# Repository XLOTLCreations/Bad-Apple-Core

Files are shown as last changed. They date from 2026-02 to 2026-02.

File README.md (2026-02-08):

Project Disclaimer and Overview

- This project has been designed by me with the sole obsession of trying to run the infamous 'Bad Apple' video (so the name) as resourcefully with least computational power as one can compared to a previous project (with relatively much more computation and features, titled 'Bad Apple' original) therefore boiling it down to it's only 'Core' aspect of video playback and from scratch without any references to any existing similar projects anywhere. All the documentation (including this one) is compiled and handwritten with outmost human accuracy without the help of AI, with that said the included Arduino test sketches and Python script are with the AI help.

- This doc helps the reader navigate through documents to develop/mod, verify and manufacture this project from start to finish. Project files include Schematic, PCB Layout and reference pictures to recreate my setup and my results, for which adhering to the highlighted sequence of steps in respective areas is highly advised. 

- For the ones who received this project from me as a gift, please ignore Doc1 and proceed with Doc2, as Doc1 strictly talks about virgin boot of this board and only requires to be done once per board.

- Project is open source software and hardware, please refer the included ECAD files for hardware insight. To my fellow hardware design engineers and experts, any design improvement suggestions are more than welcome. For the ones not so learned in the ways of hardware, may this project enlighten you with some new knowledge that you can take home. 

🎯 Project Specifications:
I am listing basic specifications for someone to decide here itself if they are interested in continuing further. No soldering required. Please note that project was designed with the intention of learning for new comers/beginners, do not @me for something the project was clearly not meant to achieve which is complexity and obscurity. Intended for kids learning in school, present it at your 'show and tell', tell me how it goes.

Connections: USB-C (Full-Speed), ICSP header (no-fit),\
Main Processor: Atmega32U4,\
Human Machine Interface: 4x tactile buttons for interaction (active LOW),\
Output: 12x9 Charlie Plexed LED Matrix driven using IS31FL3731-QF over I2C,\
Storage: W25Q128JVP 16MByte QSPI NOR Flash (video frames, game assets),\
System Working Voltage: Vsys=3.3V,\
System Clock: 8MHz,\
(over-clocking/over-volting not advised)

- Lastly, this project has no version or revision history (call me lucky to have gotten everything right the first time itself) and has an elder project by the name 'Bad Apple' which was reduced down to it's core functionality hence the reasoning behind naming this second project as 'Bad Apple Core'. Please refer to that project with several advancements and higher complexity, if not up yet then stay tuned as the project is ready and working, I am busy documenting it.

HAVE FUN LEARNING - PLAYING - EXPERIMENTING - DEVELOPING.............

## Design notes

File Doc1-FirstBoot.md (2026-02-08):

***IF YOU SKIPPED OVER 'README' PLEASE READ FIRST FOR PROJECT INSIGHT***

Programmer Used:  Arduino Nano as ISP\
Interface:  4x tactile switch push buttons\
            Up: D0 (PD2, physical pin 20)\
            Down: A5 (PF0, physical pin 41, ADC0)\
            Right: A4 (PF1, physical pin 40, ADC1)\
            Left: D11 (PB7, physical pin 12)

Notes: \
A. ISP and ICSP are one and the same, ICSP is the physical header and ISP the protocol, \
B. ISP First Boot @1MHz ~10-15 Seconds, any more time elapsed might hint at (but not necessarily) a faulty behavior, \
C. In Device Manager 'Bad Apple Core' board will enumerate as 'Arduino Leonardo' once connected through USB post finishing of the steps in this Doc1 document. 

Parts List:
Arduino NANO/UNO (for burning), respective Arduino model cable to connect to your host PC, small breadboard, jumper wires, 3x 1KOhm 1/4Watt 1% (preferred but not strict) and 3x 2KOhm 1/4Watt 1% (preferred but not strict) through hole resistors. I used 1/4W resistors being the most ubiquitious but you can easily opt to use pretty much anything below or above 1/4W power as the signals are essentially very low power themselves.

Steps:
1.0 - We need to create a 'Custom Board Definition' for our custom 'Bad Apple Core' board
1.1 - Locate your Arduino installation folder:
    Windows: `C:\Users\[YourName]\AppData\Local\Arduino15\`

1.2 - Navigate to: `packages/arduino/hardware/avr/[version]/`

1.3 - Edit `boards.txt` and add this at the end:
##############################################################
# Custom Atmega32U4 3.3V 8MHz
##############################################################

atmega32u4_33v8mhz.name=Atmega32U4 3.3V 8MHz

atmega32u4_33v8mhz.vid.0=0x2341
atmega32u4_33v8mhz.pid.0=0x8036
atmega32u4_33v8mhz.vid.1=0x2341
atmega32u4_33v8mhz.pid.1=0x0036

atmega32u4_33v8mhz.upload.tool=avrdude
atmega32u4_33v8mhz.upload.tool.default=avrdude
atmega32u4_33v8mhz.upload.protocol=avr109
atmega32u4_33v8mhz.upload.maximum_size=28672
atmega32u4_33v8mhz.upload.maximum_data_size=2560
atmega32u4_33v8mhz.upload.speed=57600
atmega32u4_33v8mhz.upload.disable_flushing=true
atmega32u4_33v8mhz.upload.use_1200bps_touch=true
atmega32u4_33v8mhz.upload.wait_for_upload_port=true

atmega32u4_33v8mhz.bootloader.tool=avrdude
atmega32u4_33v8mhz.bootloader.tool.default=avrdude
atmega32u4_33v8mhz.bootloader.low_fuses=0xFF
atmega32u4_33v8mhz.bootloader.high_fuses=0xD8
atmega32u4_33v8mhz.bootloader.extended_fuses=0xFE
atmega32u4_33v8mhz.bootloader.file=caterina/Caterina-promicro8.hex
atmega32u4_33v8mhz.bootloader.unlock_bits=0x3F
atmega32u4_33v8mhz.bootloader.lock_bits=0x2F

atmega32u4_33v8mhz.build.mcu=atmega32u4
atmega32u4_33v8mhz.build.f_cpu=8000000L
atmega32u4_33v8mhz.build.vid=0x2341
atmega32u4_33v8mhz.build.pid=0x8036
atmega32u4_33v8mhz.build.usb_product="Atmega32U4 3.3V"
atmega32u4_33v8mhz.build.board=AVR_LEONARDO
atmega32u4_33v8mhz.build.core=arduino
atmega32u4_33v8mhz.build.variant=leonardo
atmega32u4_33v8mhz.build.extra_flags={build.usb_flags}

1.4 - Most important customization is this HEX file included in the project files by the name 'Caterina-promicro8.hex' the necessary bootloader for our board's hardware configuration i.e. 3.3V @8MHz clock by SparkFun.
Navigate to ->
Arduino15\packages\arduino\hardware\avr\1.8.7\bootloaders\caterina
and paste this hex file in the 'caterina' folder along with all the others.
If you had the Arduino IDE open this is a good time to close all open tabs and relaunch the app to include all the newly added files.

2.0 - Setting up 'Arduino NANO' (UNO too will work) as ISP programmer

2.1 - Upload Arduino Nano/Uno with ArduinoISP Sketch (modified for slow clock)
      Open Arduino IDE then File → Examples → ArduinoISP → ArduinoISP

2.2 - Find this line (~ line 57): 
      #define SPI_CLOCK (1000000/6) 
      This is default. Leave the above line intact for 167kHz clock speed bootloader burning. 
      In case this speed does not work for you (very unlikely it doesn't) can try a different speed, so make the edit: 
      #define SPI_CLOCK (500000) 
      for 500kHz upload speed instead. (use if your ISP interconnect wires are very long ~1/2 - 1 foot, also note the burn time will change)

2.3 - Select: Tools → Board → Arduino Nano
      Select: Tools → Processor → ATmega328P
      Upload the sketch to Nano.

3.0 - Interface 'Arduino Nano' (ISP Master) and 'Bad Apple Core' (ISP Slave)
3.1 - Disconnect Arduino NANO from host computer (NANO OFF/unpowered) before proceeding to the step3.2,

3.2 - ***FAILING TO ADHERE TO FOLLOWING INSTRUCTIONS WILL LIKELY RESULT IN IRREPARABLE BOARD DAMAGE AND POTENTIALLY BRICK THE DEVICE***\
***!!! LEVEL SHIFT !!! THIS STEP IS PARAMOUNT***\
5V to 3.3V signal level shifting using 1K-2K resistor divider for SCK, MOSI and RST signals.\
Directly wire MISO and GND **do not level shift**. (refer to respective Arduino model pinout diagram online) Referring to the provided wiring diagram by the name 'Level Shifting' in project files will help a ton here.

3.3 - Once breadboarded the setup for the three required signals connect the Arduino NANO to host PC and select the appropriate COM port that enumerates with the Arduino model name. (not to confuse with point C in the notes section)

4.0 - Burn the Bootloader with the following Critical Settings in Arduino IDE:

4.1 - Now also connect 'Bad Apple Core' board to USB-C to power it on using either a wall adapter or host PC.
Which means now both Arduino NANO/UNO (ISP master connected to host PC) and Bad Apple Core (ISP slave) are simultaneously connected and therefore powered on.
Tools → Board: "Atmega32U4 3.3V 8MHz" (this is our Bad Apple Core now)
Tools → Programmer: "Arduino as ISP" (not "ArduinoISP.org"!)
Tools → Port: Select your Nano's COM port
Tools → Burn Bootloader

4.2 - Burn Process Serial Monitor Output @1MHz, wait ~10-15 seconds - you should see:
avrdude: verifying ...
avrdude: 1 bytes of efuse verified
avrdude: 1 bytes of hfuse verified
avrdude: 1 bytes of lfuse verified

avrdude done. Thank you.

5.1 - Troubleshooting:
"Invalid device signature" → Further slow down ISP clock to 250kHz in ArduinoISP sketch,
"Not in sync" → Check wiring, especially RESET connection,
"Property undefined" → Verify boards.txt was edited correctly and IDE restarted,

5.2 - USB Not Enumerating (Code 43)
Issue: Windows shows "Device Descriptor Request Failed"
Solution:
Wrong bootloader (16MHz on 8MHz system)
Download correct Caterina-promicro8.hex
Re-burn bootloader

After Arduino IDE prompts at successful bootloader burning, disconnect the wiring from ICSP header.

Bad Apple Core custom bootloader burn process DONE!

Next, connect the 'Bad Apple Core' board using USB-C cable to your host PC (Arduino Nano as ISP burner role completed, keep it aside) and check Win+X 'Device Manager' the 'Bad Apple Core' board should enumerate as 'Arduino Leonardo'.
This confirms all steps mentioned in this document to be successful and now we can run test sketches to verify connection integrity with all the peripherals onboard in the rare case of faulty/erroneous board assembly from the manufacturer or user mishandling scenario.

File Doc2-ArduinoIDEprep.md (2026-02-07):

**\*\*\*IF YOU SKIPPED OVER 'README' PLEASE READ FIRST FOR PROJECT INSIGHT\*\*\***

Assuming the board is loaded with the correct bootloader, therefore this document onwards one does not require any other tool except their personal computer (host computer) and the 'Bad Apple Core' board itself.

Now, the only thing one needs to do to start with coding this board is to just create a custom board definition. To do that all you need to do is add the following custom board definition into the Arduino IDE.

Steps:

1.1 - Locate your Arduino installation folder:

&nbsp;   Windows: `C:\\Users\\\[YourName]\\AppData\\Local\\Arduino15\\`

1.2 - Navigate to: `packages/arduino/hardware/avr/\[version]/`

1.3 - Edit `boards.txt` and add this at the end:

\##############################################################

\# Custom Atmega32U4 3.3V 8MHz

\##############################################################

atmega32u4\_33v8mhz.name=Atmega32U4 3.3V 8MHz

atmega32u4\_33v8mhz.vid.0=0x2341

atmega32u4\_33v8mhz.pid.0=0x8036

atmega32u4\_33v8mhz.vid.1=0x2341

atmega32u4\_33v8mhz.pid.1=0x0036

atmega32u4\_33v8mhz.upload.tool=avrdude

atmega32u4\_33v8mhz.upload.tool.default=avrdude

atmega32u4\_33v8mhz.upload.protocol=avr109

atmega32u4\_33v8mhz.upload.maximum\_size=28672

atmega32u4\_33v8mhz.upload.maximum\_data\_size=2560

atmega32u4\_33v8mhz.upload.speed=57600

atmega32u4\_33v8mhz.upload.disable\_flushing=true

atmega32u4\_33v8mhz.upload.use\_1200bps\_touch=true

atmega32u4\_33v8mhz.upload.wait\_for\_upload\_port=true

atmega32u4\_33v8mhz.bootloader.tool=avrdude

atmega32u4\_33v8mhz.bootloader.tool.default=avrdude

atmega32u4\_33v8mhz.bootloader.low\_fuses=0xFF

atmega32u4\_33v8mhz.bootloader.high\_fuses=0xD8

atmega32u4\_33v8mhz.bootloader.extended\_fuses=0xFE

atmega32u4\_33v8mhz.bootloader.file=caterina/Caterina-promicro8.hex

atmega32u4\_33v8mhz.bootloader.unlock\_bits=0x3F

atmega32u4\_33v8mhz.bootloader.lock\_bits=0x2F

atmega32u4\_33v8mhz.build.mcu=atmega32u4

atmega32u4\_33v8mhz.build.f\_cpu=8000000L

atmega32u4\_33v8mhz.build.vid=0x2341

atmega32u4\_33v8mhz.build.pid=0x8036

atmega32u4\_33v8mhz.build.usb\_product="Atmega32U4 3.3V"

atmega32u4\_33v8mhz.build.board=AVR\_LEONARDO

atmega32u4\_33v8mhz.build.core=arduino

atmega32u4\_33v8mhz.build.variant=leonardo

atmega32u4\_33v8mhz.build.extra\_flags={build.usb\_flags}

Save and quit the text file, also make sure you quit Arduino IDE by closing all it's instances open on your computer for the new board definition to load at re-launch.

Once done, re-launch your Arduino IDE as it is now ready to communicate with 'Bad Apple Core'. Just make sure you select 'Atmega32U4 3.3V 8MHz' from the drop down list of available boards from 'tools'.

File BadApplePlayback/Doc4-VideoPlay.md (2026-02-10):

\*\*\*IF YOU SKIPPED OVER 'README' PLEASE READ FIRST FOR PROJECT INSIGHT\*\*\*

I have provided two video related examples to demonstrate key possibilities with this project and to get started impressing your friends.

Titled 'BadApplePlayback' and 'ScreenMirror' does what they exactly say.

BadApplePlayback:

* Example comes with three files, two Arduino sketches first that uploads the 'Bad Apple' binary file to the flash storage on the board storage accompanied with its associated python script to send packets via USB and second Arduino sketch that displays it onto the matrix.
* Upload the 'FlashUploader.ino' Arduino sketch as usual to the board, this sketch is what instructs the MCU to read from the USB and write to the Flash simultaneously, effectively storing the video binary file on to the Flash.
* Next, open your terminal (Win+R -> cmd) in the same folder as you saved all these files i.e your python code and the 'badapple\_12x9\_30fps\_8bit.bin' raw binary video file,
* Download and install following python libraries/dependencies: pillow, mss, numpy and pyserial, you can use a single command to install them all 'pip install pillow mss pyserial numpy'.
* Type in or copy paste 'python send\_bin.py COM12 badapple\_12x9\_30fps\_8bit.bin' in the terminal, change the 'COM12' to whatever COM port your board enumerates to, wait for the computer terminal to display a successful message and terminate.
* And then lastly to play back the 'Bad Apple' video (or any video of your choice can be done this way) upload the 'BadApplePlayback.ino' Arduino sketch.

You should see a smooth display of 'Bad Apple' in gray scale at 30FPS.

ScreenMirror:

* Since we installed: pillow, mss, numpy and pyserial in the last example we can skip this step,
* Upload the 'ScreenMirror.ino' sketch to the board, you can edit 'matrix.drawPixel(x, y, brightness / 2);  // Dim by 50%' line in the sketch to desired LED Matrix brightness. Once uploaded it is best to quit all open 'Arduino IDE' instances or at least make sure the serial monitor is not open and reading the COM port. Board blinks with center pixel when waiting for frame reception from host PC.
* Launch cmd in this folder containing the 'screen\_mirror.py' Python file and in terminal type in the command 'python screen\_mirror.py COM12'. Change COM12 with your enumerated COM port.

 You can play with the python code parameters such as:
CAPTURE\_REGION = {'left': 100, 'top': 100, 'width': 800, 'height': 600}

 TARGET\_FPS = 20  # Lower for stability, higher for smoothness

 CAPTURE\_REGION = {'left': 0, 'top': 0, 'width': 960, 'height': 540} #Top-left quadrant on a 1920×1080 monitor/display

 CAPTURE\_REGION = {'left': 460, 'top': 240, 'width': 1000, 'height': 600} #Screen center capture on a 1920×1080 monitor/display

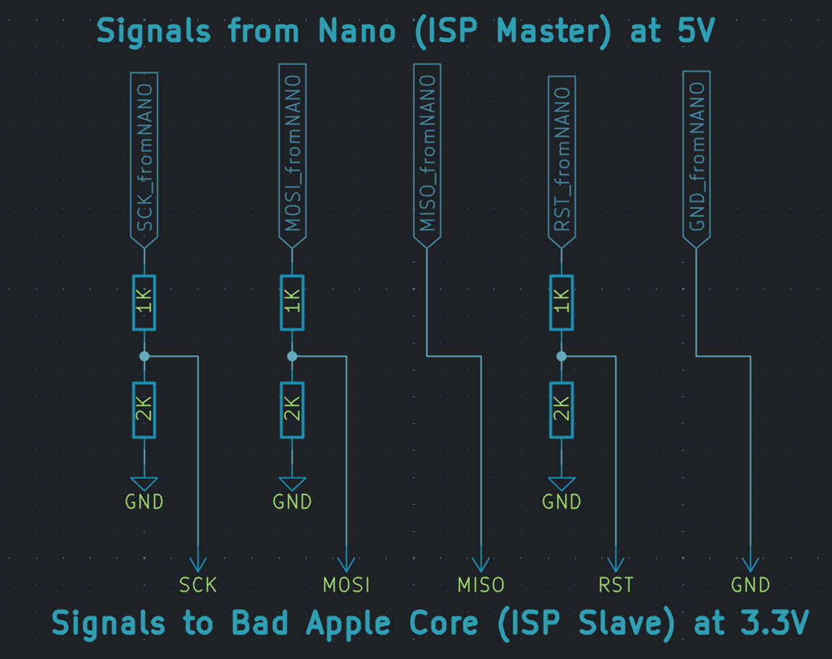
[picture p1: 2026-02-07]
Level Shifting.png

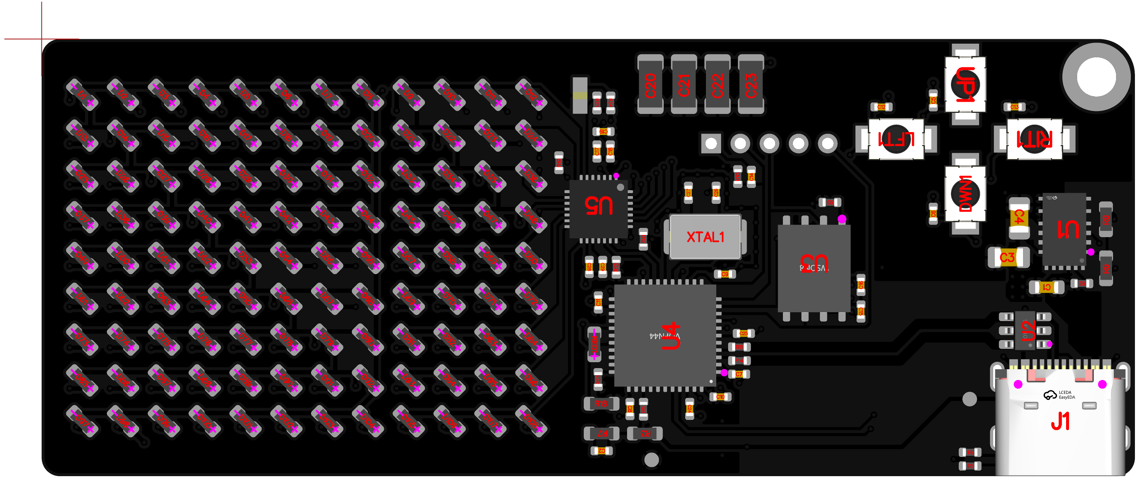
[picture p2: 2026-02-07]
ProductionFiles/ReferrenceBoardView.png

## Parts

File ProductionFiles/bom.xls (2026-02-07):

Comment | Designator | Footprint | JLCPCB Part #
SW_Push | DWN1,LFT1,RIT1,UP1 | PushButton_4x3mm_Custom | C720477
22uF | C3,C4 | 0805 | C45783
4K7 | R12,R13 | 0402 | C25900
10K | R10,R23,R9 | 0402 | C25744
100u | C20,C21,C22,C23 | 1206 | C15008
100K | R19,R2 | 0402 | C25741
LED_Small | RED1,D1,D10,D100,D101,D102,D103,D104,D105,D106,D107,D108,D11,D12,D13,D14,D15,D16,D17,D18,D19,D2,D20,D21,D22,D23,D24,D25,D26,D27,D28,D29,D3,D30,D31,D32,D33,D34,D35,D36,D37,D38,D39,D4,D40,D41,D42,D43,D44,D45,D46,D47,D48,D49,D5,D50,D51,D52,D53,D54,D55,D56,D57,D58,D59,D6,D60,D61,D62,D63,D64,D65,D66,D67,D68,D69,D7,D70,D71,D72,D73,D74,D75,D76,D77,D78,D79,D8,D80,D81,D82,D83,D84,D85,D86,D87,D88,D89,D9,D90,D91,D92,D93,D94,D95,D96,D97,D98,D99 | 0603 | C2286
75K | R6 | 0603 | C23242
USBLC6-2SC6 | U2 | SOT-23-6 | C7519
Crystal | XTAL1 | Crystal_SMD_5032-2Pin_5.0x3.2mm | C115962
10uF | C1 | 0603 | C19702
75 | R18 | 0603 | C4275
4u7 | C16 | 0402 | C23733
33pF | C26,C27 | 0402 | C1562
1uF | C10,C11,C19,C25 | 0402 | C52923
220nF | C29 | 0402 | C16772
ATmega32U4-M | U4 | QFN-44-1EP_7x7mm_P0.5mm_EP5.2x5.2mm | C112161
5K6 | R3 | 0603 | C23189
24K | R8 | 0603 | C23352
1K | R5 | 0402 | C11702
100nF | C12,C13,C14,C15,C17,C18,C2,C24,C28,C5,C6,C7,C8,C9 | 0402 | C1525
5.1K | R1,R4 | 0402 | C25905
MPM3610GQV-Z | U1 | QFN3p0x5p0x1p6_MPM3610_MNP | C5183856
IS31FL3731-QF | U5 | QFN-28-1EP_4x4mm_P0.4mm_EP2.3x2.3mm | C191206
22 | R11,R14 | 0402 | C25092
W25Q128JVP | U3 | WSON-8-1EP_6x5mm_P1.27mm_EP3.4x4.3mm | C190862
10K | R7 | 0603 | C25804
USB_C_Receptacle_USB2.0_14P | J1 | USB-C_Custom | C2927037
20K | R24,R25 | 0402 | C25765

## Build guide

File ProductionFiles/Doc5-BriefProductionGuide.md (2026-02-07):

\*\*\*IF YOU SKIPPED OVER 'README and Doc1' PLEASE READ FIRST FOR PROJECT INSIGHT\*\*\*

* For the ones who want to reproduce this design please note that this is meant to be done with prior knowledge of these processes for which you can watch several YouTube videos on PCB manufacturing and Turnkey assembly. I personally have had a lot of good Turnkey Manufacturing experience particularly with JLCPCB (not sponsored) and so in my production files I have BOM with JLCPCB or LCSC part numbers for all of the devices, silicon, and components.

* If you modify anything on the physical layout of the PCB Please be aware that you will have to generate your own production files in your tool of choice as my provided files will be of no use. For the same you can watch numerous videos online guiding through steps.

* To save some time watching videos I am listing generic steps here to usher oneself into production. Although I advice to proceed with caution if had no prior experience producing physical designs. No need to be alarmed as nothing is a health hazard here and you also get a full quote/pricing at the end before paying for the manufacturing services.

With those instructions out of the way we can move onto actual manufacturing steps.

1. Visit https://jlcpcb.com/ and create account, afterwards click on 'Order Now',
2. Drag and Drop the 'Bad\_Apple\_Core.zip' zip file into the field that says 'Add gerber file', this .zip file is your 'Gerber' file,
3. Intermediate Step: If you just select your desired board color from the available color selection purely for aesthetics it comes at no additional cost.

 	An important thing to know here is that many hobby designers also choose to assemble their own boards by placing all the parts on the bare PCB by themselves. So if you checkout at this step here and now you will receive bare flat boards and you will have yourself a good learning challenge for assembling your own PCB.
But because I am aware of the size of these components (majority of them being 0402 package) I would advice go all the way and get the boards fully assembled.
4. Scroll down all the way and turn on 'PCB Assembly' option, here you can choose quantity of boards assembled where minimum is 2, also you may choose to turn on 'Confirm Parts Placement' option for further verification of your files once processed and passed by the JLCPCB engineers. Click Next, and Next again.

5\. Once on the page with two separate fields asking for 'BOM' and 'CPL' files drag and drop the respective files into the website fields. Click 'Process BOM \& CPL'.
6. Once processed you can edit the individual parts in this window which is basically your BOM processed view on website. Check all the boxes and proceed.

\*\*\*ALL THE BOXES NEED TO BE CHECKED BEFORE NEXT STEP\*\*\*

7\. You will see a 3D render of your board here in green color regardless of your chosen color at the very start, the chosen color reflects later. In this 3D render please cross verify with the included picture titled 'ReferrenceBoardView' and rotate any individual components to match what is shown in the picture (you will likely not need to rotate any component but double checking is a good failsafe insurance). Click Next,

8\. Select a suitable Product Description, you can choose something like 'Reserch\\Education\\DIY\\Entertainment' -> 'DIY Hobby Circuit Board' and Save to Cart, from here you can pay, select shipment partner and pay for the services.

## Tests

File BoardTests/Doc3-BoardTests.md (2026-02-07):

\*\*\*IF YOU SKIPPED OVER 'README' PLEASE READ FIRST FOR PROJECT INSIGHT\*\*\*

The tests described in this doc are not strictly necessary, although they will come handy while troubleshooting the board, in which case the user might want to test all the subsystems individually to rule out any physical malfunctions or incurred damages to the board. This includes any under chip damages and therefore invisible.

1.0 - LED Blink Sketch:

      'Bad Apple Core' has a board health/sanity test Red LED on Digital pin#6.

1.1 - In Arduino IDE:

Tools → Board: "Atmega32U4 3.3V 8MHz"

Tools → Port: COM10 (or whichever COM port it enumerates as, this is your newly flashed Bad Apple Core board)

 void setup() {

     pinMode(6, OUTPUT);

   }

   void loop() {

     digitalWrite(6, HIGH);

     delay(300);

     digitalWrite(6, LOW);

     delay(300);

   }

1.2 - Copy paste the above sketch in Arduino IDE, compile and upload.

The LED should blink at 300msec on/off rate.
First signs of life...

2.0 - Move onto testing Matrix driver with some LED Matrix pattern sketches included. Start by searching for and installing 'Adafruit IS31FL3731 Library' and 'Adafruit GFX Library'. Note that LED Matrix sub-system features a user accessible active-high shutdown control on digital pin#9, if LED matrix ever flickers during large file uploads to and from the Flash Memory onboard (unlikely but not impossible).

3.0 - Next we will attempt to establish communication with the onboard 16MByte NOR Flash storage. Massive amount of storage for this board capability, memory for days...

3.1 - Start by installing SPIMemory library in Arduino IDE:

Arduino IDE → Sketch → Include Library → Manage Libraries

Search: "SPIMemory"

Install: "SPIMemory by Prajwal Bhattaram (Marzogh)"

Now go ahead and upload the included Flash test sketch while reading the Serial Monitor Output for confirmation. The output should look like:

=== Flash Test Complete ===

Flash is ready for video storage!

4.0 - Last and Final we will check the four push-buttons with the included sketch.

5.0 - As a bonus feature and completely optional, the design features USB bus voltage monitoring on the pin# ADC7 Analog Input 0. This feature comes in handy when dealing with a very weak PC USB port. User can utilize this to frequently monitor the USB bus voltage droop to not overload the PC USB port and maybe cause any very unlikely damages to the host PC by modifying the LED Matrix brightness to a safer level.

Ratio: Vmeasured = Vbus × 0.641, where Vbus = 5.0 - 5.1 Volts.

Hence concludes all our board tests...!

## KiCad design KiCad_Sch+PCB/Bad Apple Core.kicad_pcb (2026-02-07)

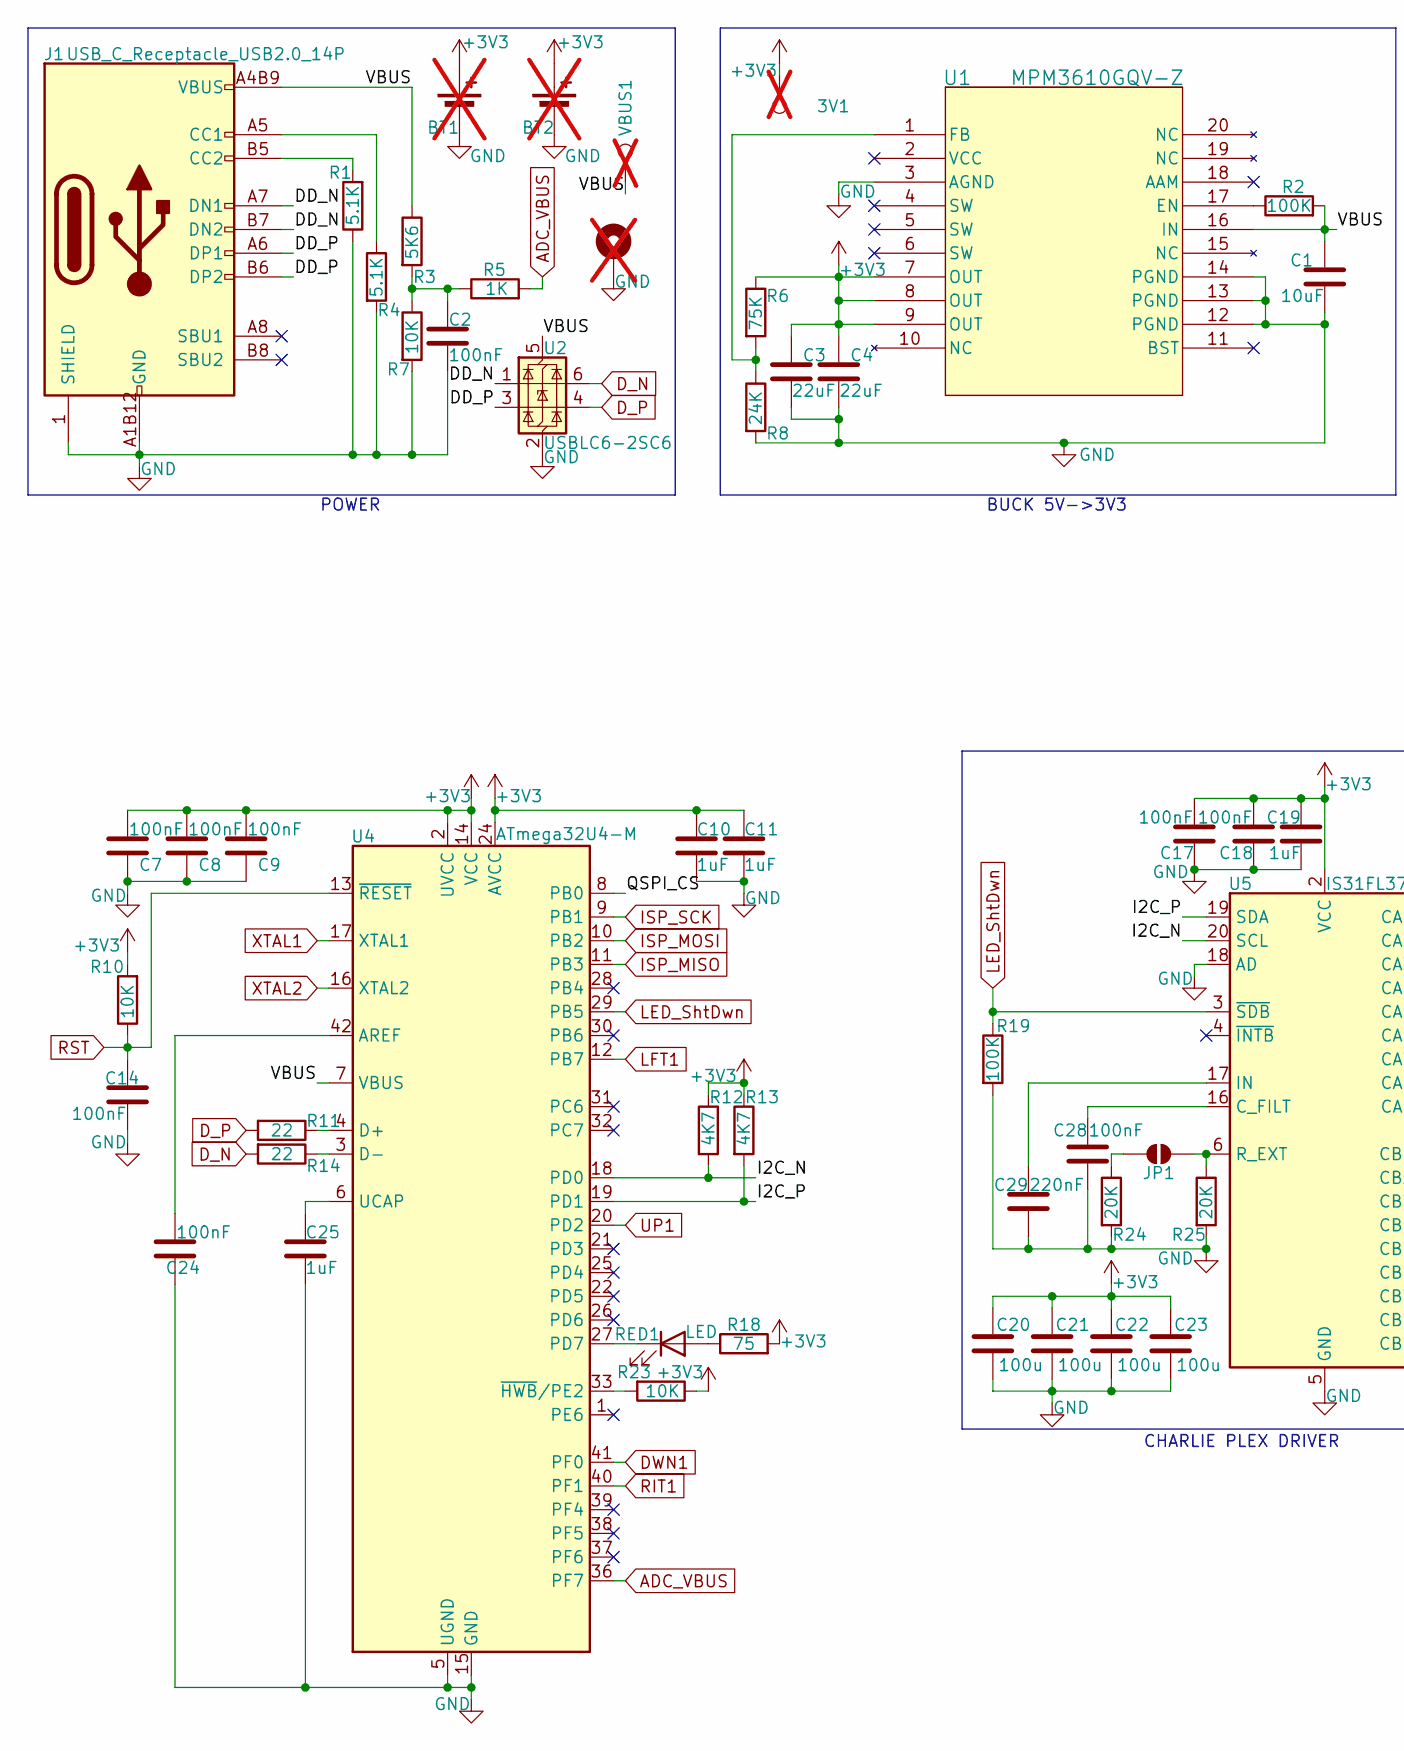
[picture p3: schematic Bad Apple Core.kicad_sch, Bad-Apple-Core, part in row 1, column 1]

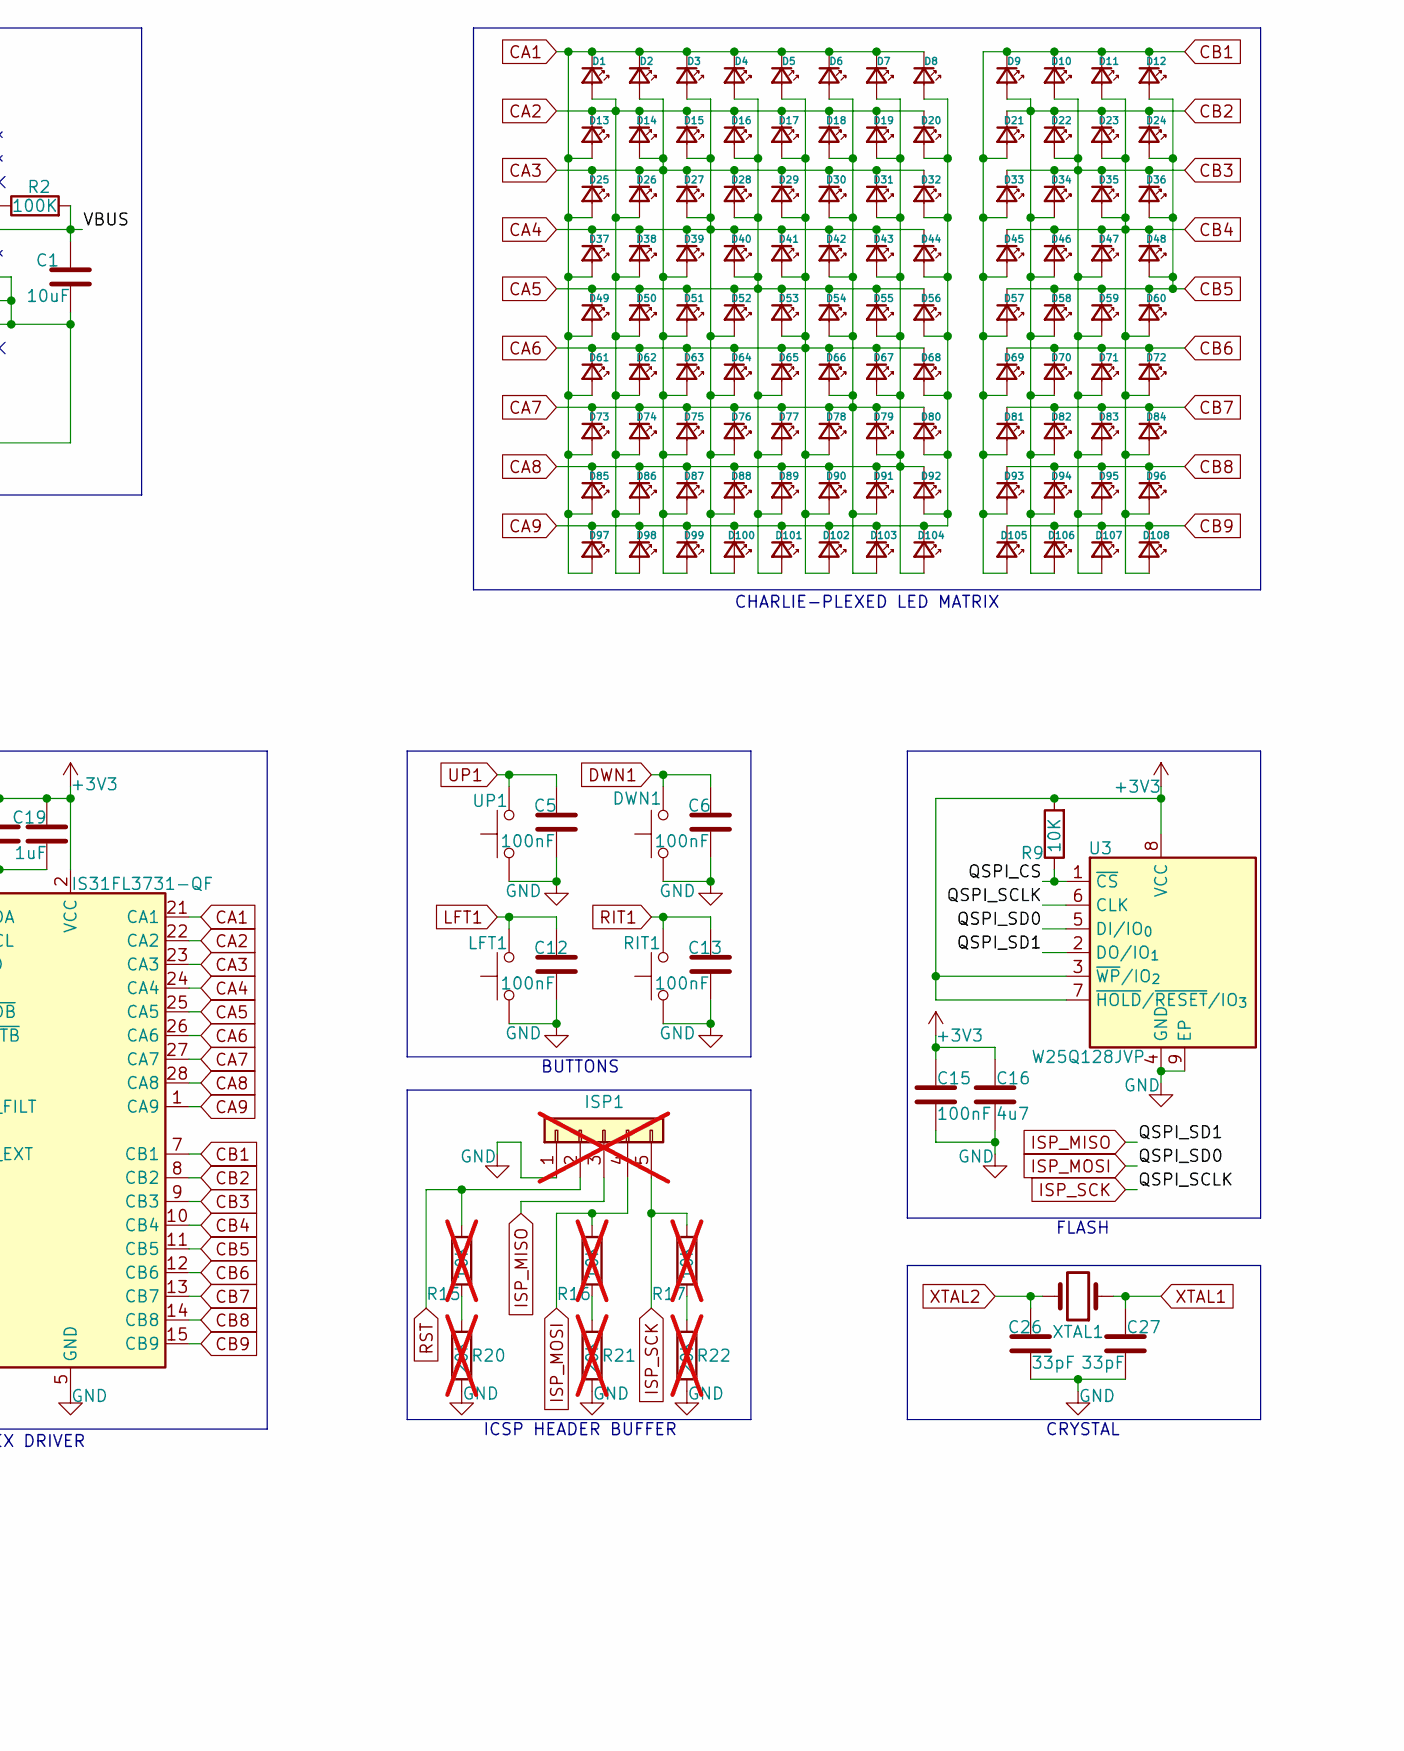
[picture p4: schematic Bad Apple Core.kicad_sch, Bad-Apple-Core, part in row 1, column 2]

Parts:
3V1: TestPoint; TestPoint_Pad_D1.0mm; not fitted
BT1: Battery_Cell; BatteryHolder_Multicomp_BC-2001_1x2032; not fitted
BT2: Battery_Cell; BatteryHolder_Keystone_3008_1x2450; not fitted
C1: 10uF; C_0603_1608Metric; JLCPCB# C19702
C2, C5, C6, C7, C8, C9, C12, C13, C14, C15, C17, C18, C24, C28: 100nF; C_0402_1005Metric; JLCPCB# C1525
C3, C4: 22uF; C_0805_2012Metric; JLCPCB# C45783
C10, C11, C19, C25: 1uF; C_0402_1005Metric; JLCPCB# C52923
C16: 4u7; C_0402_1005Metric; JLCPCB# C23733
C20, C21, C22, C23: 100u; C_1206_3216Metric; JLCPCB# C15008
C26, C27: 33pF; C_0402_1005Metric; JLCPCB# C1562
C29: 220nF; C_0402_1005Metric; JLCPCB# C16772
D1, D2, D3, D4, D5, D6, D7, D8, D9, D10, D11, D12, D13, D14, D15, D16, D17, D18, D19, D20, D21, D22, D23, D24, D25, D26, D27, D28, D29, D30, D31, D32, D33, D34, D35, D36, D37, D38, D39, D40, D41, D42, D43, D44, D45, D46, D47, D48, D49, D50, D51, D52, D53, D54, D55, D56, D57, D58, D59, D60, D61, D62, D63, D64, D65, D66, D67, D68, D69, D70, D71, D72, D73, D74, D75, D76, D77, D78, D79, D80, D81, D82, D83, D84, D85, D86, D87, D88, D89, D90, D91, D92, D93, D94, D95, D96, D97, D98, D99, D100, D101, D102, D103, D104, D105, D106, D107, D108: LED_Small; LED_0603_1608Metric; JLCPCB# C2290
DWN1: SW_Push; PushButton_4x3mm_Custom; JLCPCB# C720477
H1: MountingHole_Pad; MountingHole_2.7mm_M2.5_DIN965_Pad; JLCPCB# N/A; not fitted
ISP1: Conn_01x05; PinHeader_1x05_P2.00mm_Vertical; not fitted
J1: USB_C_Receptacle_USB2.0_14P; USB-C_Custom; JLCPCB# C2927037
JP1: SolderJumper_2_Open; SolderJumper-2_P1.3mm_Open_Pad1.0x1.5mm
LFT1: SW_Push; PushButton_4x3mm_Custom; JLCPCB# C720477
R1, R4: 5.1K; R_0402_1005Metric; JLCPCB# C25905
R2, R19: 100K; R_0402_1005Metric; JLCPCB# C25741
R3: 5K6; R_0603_1608Metric; JLCPCB# C23189
R5: 1K; R_0402_1005Metric; JLCPCB# C11702
R6: 75K; R_0603_1608Metric; JLCPCB# C23242
R7: 10K; R_0603_1608Metric; JLCPCB# C25804
R8: 24K; R_0603_1608Metric; JLCPCB# C23352
R9, R10, R23: 10K; R_0402_1005Metric; JLCPCB# C25744
R11, R14: 22; R_0402_1005Metric; JLCPCB# C25092
R12, R13: 4K7; R_0402_1005Metric; JLCPCB# C25900
R15, R16, R17: 10K; R_0402_1005Metric; JLCPCB# C25744; not fitted
R18: 75; R_0603_1608Metric; JLCPCB# C4275
R20, R21, R22: 20K; R_0402_1005Metric; JLCPCB# C25765; not fitted
R24, R25: 20K; R_0402_1005Metric; JLCPCB# C25765
RED1: LED; LED_0603_1608Metric; JLCPCB# C2286
RIT1: SW_Push; PushButton_4x3mm_Custom; JLCPCB# C720477
U1: MPM3610GQV-Z; QFN3p0x5p0x1p6_MPM3610_MNP; JLCPCB# C5183856
U2: USBLC6-2SC6; SOT-23-6; JLCPCB# C7519
U3: W25Q128JVP; WSON-8-1EP_6x5mm_P1.27mm_EP3.4x4.3mm; JLCPCB# C190862
U4: ATmega32U4-M; QFN-44-1EP_7x7mm_P0.5mm_EP5.2x5.2mm; MFR.Part # ATMEGA32U4-MU; JLCPCB# C112161
U5: IS31FL3731-QF; QFN-28-1EP_4x4mm_P0.4mm_EP2.3x2.3mm; JLCPCB# C191206
UP1: SW_Push; PushButton_4x3mm_Custom; JLCPCB# C720477
VBUS1: TestPoint; TestPoint_Pad_D1.0mm; not fitted
XTAL1: Crystal; Crystal_SMD_5032-2Pin_5.0x3.2mm; JLCPCB# C115962

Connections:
+3V3: 3V1.1, BT1.1 (+), BT2.1 (+), C3.1, C4.1, C7.1, C8.1, C9.1, C10.1, C11.1, C15.1, C16.1, C17.1, C18.1, C19.1, C20.1, C21.1, C22.1, C23.1, R6.1, R9.2, R10.2, R12.1, R13.1, R18.2, R23.1, U1.7 (OUT), U1.8 (OUT), U1.9 (OUT), U3.3 (~WP/IO_{2}), U3.7 (~HOLD/~RESET/IO_{3}), U3.8 (VCC), U4.2 (UVCC), U4.14 (VCC), U4.24 (AVCC), U4.34 (VCC), U4.44 (AVCC), U5.2 (VCC)
/DD_N: J1.A7 (DN1), J1.B7 (DN2), U2.1 (I/O1)
/DD_P: J1.A6 (DP1), J1.B6 (DP2), U2.3 (I/O2)
/I2C_N: R12.2, U4.18 (PD0), U5.20 (SCL)
/I2C_P: R13.2, U4.19 (PD1), U5.19 (SDA)
/QSPI_CS: R9.1, U3.1 (~CS), U4.8 (PB0)
/VBUS: C1.1, J1.A4B9 (VBUS), J1.B4A9 (VBUS), R2.2, R3.1, U1.16 (IN), U2.5 (VBUS), U4.7 (VBUS), VBUS1.1
ADC_VBUS: R5.2, U4.36 (PF7)
CA1: D1.1 (K), D2.1 (K), D3.1 (K), D4.1 (K), D5.1 (K), D6.1 (K), D7.1 (K), D8.1 (K), D13.2 (A), D25.2 (A), D37.2 (A), D49.2 (A), D61.2 (A), D73.2 (A), D85.2 (A), D97.2 (A), U5.21 (CA1)
CA2: D1.2 (A), D13.1 (K), D14.1 (K), D15.1 (K), D16.1 (K), D17.1 (K), D18.1 (K), D19.1 (K), D20.1 (K), D26.2 (A), D38.2 (A), D50.2 (A), D62.2 (A), D74.2 (A), D86.2 (A), D98.2 (A), U5.22 (CA2)
CA3: D2.2 (A), D14.2 (A), D25.1 (K), D26.1 (K), D27.1 (K), D28.1 (K), D29.1 (K), D30.1 (K), D31.1 (K), D32.1 (K), D39.2 (A), D51.2 (A), D63.2 (A), D75.2 (A), D87.2 (A), D99.2 (A), U5.23 (CA3)
CA4: D3.2 (A), D15.2 (A), D27.2 (A), D37.1 (K), D38.1 (K), D39.1 (K), D40.1 (K), D41.1 (K), D42.1 (K), D43.1 (K), D44.1 (K), D52.2 (A), D64.2 (A), D76.2 (A), D88.2 (A), D100.2 (A), U5.24 (CA4)
CA5: D4.2 (A), D16.2 (A), D28.2 (A), D40.2 (A), D49.1 (K), D50.1 (K), D51.1 (K), D52.1 (K), D53.1 (K), D54.1 (K), D55.1 (K), D56.1 (K), D65.2 (A), D77.2 (A), D89.2 (A), D101.2 (A), U5.25 (CA5)
CA6: D5.2 (A), D17.2 (A), D29.2 (A), D41.2 (A), D53.2 (A), D61.1 (K), D62.1 (K), D63.1 (K), D64.1 (K), D65.1 (K), D66.1 (K), D67.1 (K), D68.1 (K), D78.2 (A), D90.2 (A), D102.2 (A), U5.26 (CA6)
CA7: D6.2 (A), D18.2 (A), D30.2 (A), D42.2 (A), D54.2 (A), D66.2 (A), D73.1 (K), D74.1 (K), D75.1 (K), D76.1 (K), D77.1 (K), D78.1 (K), D79.1 (K), D80.1 (K), D91.2 (A), D103.2 (A), U5.27 (CA7)
CA8: D7.2 (A), D19.2 (A), D31.2 (A), D43.2 (A), D55.2 (A), D67.2 (A), D79.2 (A), D85.1 (K), D86.1 (K), D87.1 (K), D88.1 (K), D89.1 (K), D90.1 (K), D91.1 (K), D92.1 (K), D104.2 (A), U5.28 (CA8)
CA9: D8.2 (A), D20.2 (A), D32.2 (A), D44.2 (A), D56.2 (A), D68.2 (A), D80.2 (A), D92.2 (A), D97.1 (K), D98.1 (K), D99.1 (K), D100.1 (K), D101.1 (K), D102.1 (K), D103.1 (K), D104.1 (K), U5.1 (CA9)
CB1: D9.1 (K), D10.1 (K), D11.1 (K), D12.1 (K), D21.2 (A), D33.2 (A), D45.2 (A), D57.2 (A), D69.2 (A), D81.2 (A), D93.2 (A), D105.2 (A), U5.7 (CB1)
CB2: D9.2 (A), D21.1 (K), D22.1 (K), D23.1 (K), D24.1 (K), D34.2 (A), D46.2 (A), D58.2 (A), D70.2 (A), D82.2 (A), D94.2 (A), D106.2 (A), U5.8 (CB2)
CB3: D10.2 (A), D22.2 (A), D33.1 (K), D34.1 (K), D35.1 (K), D36.1 (K), D47.2 (A), D59.2 (A), D71.2 (A), D83.2 (A), D95.2 (A), D107.2 (A), U5.9 (CB3)
CB4: D11.2 (A), D23.2 (A), D35.2 (A), D45.1 (K), D46.1 (K), D47.1 (K), D48.1 (K), D60.2 (A), D72.2 (A), D84.2 (A), D96.2 (A), D108.2 (A), U5.10 (CB4)
CB5: D12.2 (A), D24.2 (A), D36.2 (A), D48.2 (A), D57.1 (K), D58.1 (K), D59.1 (K), D60.1 (K), U5.11 (CB5)
CB6: D69.1 (K), D70.1 (K), D71.1 (K), D72.1 (K), U5.12 (CB6)
CB7: D81.1 (K), D82.1 (K), D83.1 (K), D84.1 (K), U5.13 (CB7)
CB8: D93.1 (K), D94.1 (K), D95.1 (K), D96.1 (K), U5.14 (CB8)
CB9: D105.1 (K), D106.1 (K), D107.1 (K), D108.1 (K), U5.15 (CB9)
DWN1: C6.1, DWN1.1, U4.41 (PF0)
D_N: R14.2, U2.6 (I/O1)
D_P: R11.2, U2.4 (I/O2)
GND: BT1.2 (-), BT2.2 (-), C1.2, C2.2, C3.2, C4.2, C5.2, C6.2, C7.2, C8.2, C9.2, C10.2, C11.2, C12.2, C13.2, C14.2, C15.2, C16.2, C17.2, C18.2, C19.2, C20.2, C21.2, C22.2, C23.2, C24.2, C25.2, C26.2, C27.2, C28.2, C29.2, DWN1.2, H1.1, ISP1.1, J1.1 (SHIELD), J1.2 (SHIELD), J1.3 (SHIELD), J1.4 (SHIELD), J1.A1B12 (GND), J1.B1A12 (GND), LFT1.1, R1.1, R4.2, R7.2, R8.2, R19.2, R20.1, R21.1, R22.1, R24.2, R25.2, RIT1.1, U1.3 (AGND), U1.12 (PGND), U1.13 (PGND), U1.14 (PGND), U2.2 (GND), U3.4 (GND), U3.9 (EP), U4.5 (UGND), U4.15 (GND), U4.23 (GND), U4.35 (GND), U4.43 (GND), U4.45 (GND), U5.5 (GND), U5.18 (AD), U5.29 (GND), UP1.1
ISP_MISO: ISP1.3, U3.2 (DO/IO_{1}), U4.11 (PB3)
ISP_MOSI: ISP1.4, R16.2, U3.5 (DI/IO_{0}), U4.10 (PB2)
ISP_SCK: ISP1.5, R17.2, U3.6 (CLK), U4.9 (PB1)
LED_ShtDwn: R19.1, U4.29 (PB5), U5.3 (~SDB)
LFT1: C12.1, LFT1.2, U4.12 (PB7)
unnamed: C2.1, R3.2, R5.1, R7.1
unnamed: J1.A5 (CC1), R4.1
unnamed: J1.B5 (CC2), R1.2
unnamed: JP1.1 (A), R24.1
unnamed: JP1.2 (B), R25.1, U5.6 (R_EXT)
unnamed: R15.1, R20.2
unnamed: R16.1, R21.2
unnamed: R17.1, R22.2
unnamed: R18.1, RED1.2 (A)
unnamed: RED1.1 (K), U4.27 (PD7)
unnamed: R2.1, U1.17 (EN)
unnamed: R6.2, R8.1, U1.1 (FB)
unnamed: C24.1, U4.42 (AREF)
unnamed: R11.1, U4.4 (D+)
unnamed: R14.1, U4.3 (D-)
unnamed: C25.1, U4.6 (UCAP)
unnamed: R23.2, U4.33 (~HWB/PE2)
unnamed: C28.1, U5.16 (C_FILT)
unnamed: C29.1, U5.17 (IN)
RIT1: C13.1, RIT1.2, U4.40 (PF1)
RST: C14.1, ISP1.2, R10.1, R15.2, U4.13 (~RESET)
UP1: C5.1, U4.20 (PD2), UP1.2
XTAL1: C27.1, U4.17 (XTAL1), XTAL1.1
XTAL2: C26.1, U4.16 (XTAL2), XTAL1.2

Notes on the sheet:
CHARLIE-PLEXED LED MATRIX
FLASH
ICSP HEADER BUFFER
CHARLIE PLEX DRIVER
BUTTONS
BUCK 5V->3V3
POWER
CRYSTAL

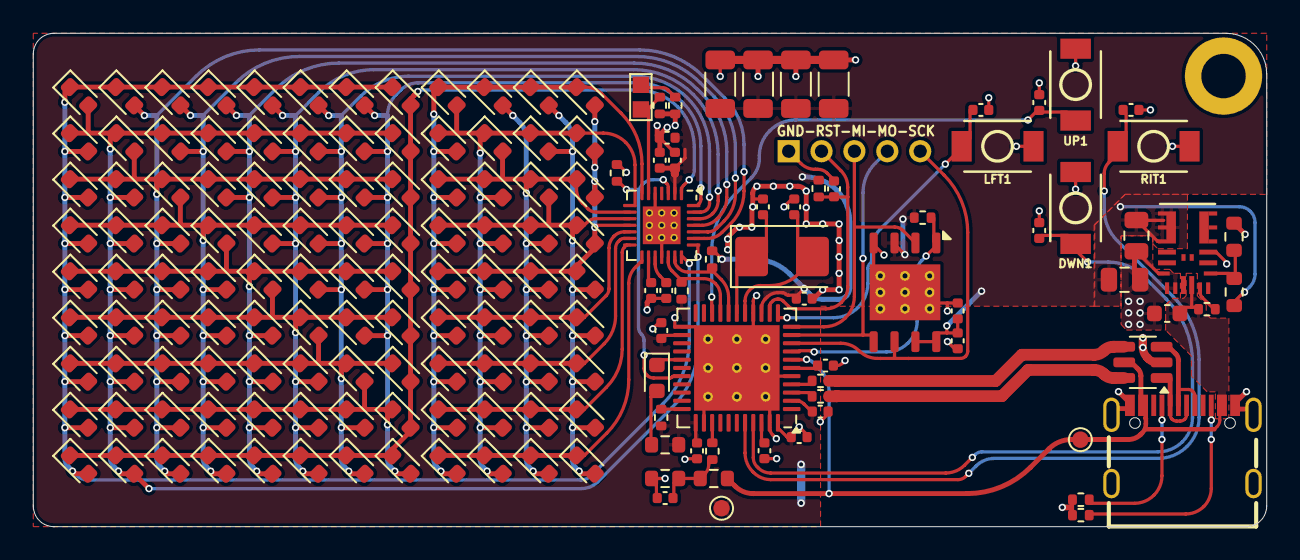
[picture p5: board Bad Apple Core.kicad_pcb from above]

Board: 2 copper layers, 75.0 x 30.0 mm, 174 parts (1 on the bottom side), 56 nets.

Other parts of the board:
XLOTL CREATIONS: XLOTL Creations

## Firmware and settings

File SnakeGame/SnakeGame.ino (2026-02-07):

/*
 * SNAKE GAME
 * Classic snake game on 12x9 LED matrix
 * 
 * Controls:
 * - Up:    D0  (move up)
 * - Down:  A5  (move down)
 * - Right: A4  (move right)
 * - Left:  D11 (move left)
 * 
 * Rules:
 * - Eat food to grow
 * - Don't hit walls or yourself
 * - Game over = restart
 */

#include <Wire.h>
#include <Adafruit_GFX.h>
#include <Adafruit_IS31FL3731.h>

// Pin definitions
#define BTN_UP    0
#define BTN_DOWN  A5
#define BTN_RIGHT A4
#define BTN_LEFT  11
#define SDB_PIN   9

// Game constants
#define GRID_WIDTH  12
#define GRID_HEIGHT 9
#define MAX_SNAKE_LENGTH 108  // Max possible on 12x9

Adafruit_IS31FL3731 matrix = Adafruit_IS31FL3731();

// Snake structure
struct Point {
  int8_t x;
  int8_t y;
};

Point snake[MAX_SNAKE_LENGTH];
uint8_t snakeLength = 3;
Point food;
int8_t dirX = 1;  // Start moving right
int8_t dirY = 0;
uint16_t score = 0;
bool gameOver = false;
unsigned long lastMoveTime = 0;
uint16_t moveDelay = 500;  // milliseconds between moves

void setup() {
  // Enable IS31FL3731
  pinMode(SDB_PIN, OUTPUT);
  digitalWrite(SDB_PIN, HIGH);
  delay(5);
  
  Serial.begin(115200);
  delay(1000);
  
  Serial.println("=== SNAKE GAME ===");
  Serial.println("Use arrow buttons to move");
  Serial.println("Eat food to grow!");
  Serial.println();
  
  // Setup buttons
  pinMode(BTN_UP, INPUT_PULLUP);
  pinMode(BTN_DOWN, INPUT_PULLUP);
  pinMode(BTN_RIGHT, INPUT_PULLUP);
  pinMode(BTN_LEFT, INPUT_PULLUP);
  
  // Initialize LED matrix
  if (!matrix.begin(0x74)) {
    Serial.println("IS31FL3731 not found!");
    while (1);
  }
  
  matrix.clear();
  
  // Seed random number generator
  randomSeed(analogRead(A0));
  
  // Start game
  initGame();
  
  Serial.println("Game started! Score: 0");
}

void initGame() {
  // Reset snake to center, length 3, moving right
  snakeLength = 3;
  snake[0] = {6, 4};  // Head
  snake[1] = {5, 4};
  snake[2] = {4, 4};  // Tail
  
  dirX = 1;
  dirY = 0;
  score = 0;
  gameOver = false;
  moveDelay = 300;
  
  // Spawn first food
  spawnFood();
}

void spawnFood() {
  // Find empty spot for food
  bool validSpot = false;
  
  while (!validSpot) {
    food.x = random(0, GRID_WIDTH);
    food.y = random(0, GRID_HEIGHT);
    
    // Check if food spawned on snake
    validSpot = true;
    for (uint8_t i = 0; i < snakeLength; i++) {
      if (snake[i].x == food.x && snake[i].y == food.y) {
        validSpot = false;
        break;
      }
    }
  }
  
  Serial.print("Food spawned at (");
  Serial.print(food.x);
  Serial.print(", ");
  Serial.print(food.y);
  Serial.println(")");
}

void handleInput() {
  // Read buttons (active LOW)
  bool up = (digitalRead(BTN_UP) == LOW);
  bool down = (digitalRead(BTN_DOWN) == LOW);
  bool right = (digitalRead(BTN_RIGHT) == LOW);
  bool left = (digitalRead(BTN_LEFT) == LOW);
  
  // Change direction (prevent 180-degree turns)
  if (up && dirY != 1) {
    dirX = 0;
    dirY = -1;
  } else if (down && dirY != -1) {
    dirX = 0;
    dirY = 1;
  } else if (right && dirX != -1) {
    dirX = 1;
    dirY = 0;
  } else if (left && dirX != 1) {
    dirX = -1;
    dirY = 0;
  }
}

void moveSnake() {
  // Calculate new head position
  Point newHead;
  newHead.x = snake[0].x + dirX;
  newHead.y = snake[0].y + dirY;
  
  // Check wall collision
  if (newHead.x < 0 || newHead.x >= GRID_WIDTH || 
      newHead.y < 0 || newHead.y >= GRID_HEIGHT) {
    gameOver = true;
    Serial.println("GAME OVER! Hit wall!");
    Serial.print("Final Score: ");
    Serial.println(score);
    return;
  }
  
  // Check self collision
  for (uint8_t i = 0; i < snakeLength; i++) {
    if (snake[i].x == newHead.x && snake[i].y == newHead.y) {
      gameOver = true;
      Serial.println("GAME OVER! Hit yourself!");
      Serial.print("Final Score: ");
      Serial.println(score);
      return;
    }
  }
  
  // Check food collision
  bool ateFood = (newHead.x == food.x && newHead.y == food.y);
  
  if (ateFood) {
    score++;
    Serial.print("Food eaten! Score: ");
    Serial.println(score);
    
    // Speed up slightly
    if (moveDelay > 100) {
      moveDelay -= 10;
    }
    
    // Grow snake (don't remove tail)
    snakeLength++;
    if (snakeLength >= MAX_SNAKE_LENGTH) {
      // YOU WIN!
      Serial.println("YOU WIN! Maximum length reached!");
      gameOver = true;
      return;
    }
    
    spawnFood();
  }
  
  // Move snake body
  for (int i = snakeLength - 1; i > 0; i--) {
    snake[i] = snake[i - 1];
  }
  
  // Move head
  snake[0] = newHead;
  
  // If didn't eat food, we already moved tail by shifting array
  // If ate food, snake grew by 1
}

void drawGame() {
  matrix.clear();
  
  // Draw snake body
  for (uint8_t i = 1; i < snakeLength; i++) {
    matrix.drawPixel(snake[i].x, snake[i].y, 150);
  }
  
  // Draw snake head (brighter)
  matrix.drawPixel(snake[0].x, snake[0].y, 255);
  
  // Draw food (blink every 500ms)
  if ((millis() / 250) % 2 == 0) {
    matrix.drawPixel(food.x, food.y, 200);
  }
}

void showGameOver() {
  // Flash screen 3 times
  for (uint8_t flash = 0; flash < 3; flash++) {
    matrix.clear();
    delay(200);
    
    // Fill screen
    for (uint8_t y = 0; y < GRID_HEIGHT; y++) {
      for (uint8_t x = 0; x < GRID_WIDTH; x++) {
        matrix.drawPixel(x, y, 100);
      }
    }
    delay(200);
  }
  
  matrix.clear();
  
  // Show score as filled pixels (up to 108)
  uint16_t pixelsToShow = min(score, (uint16_t)108);
  uint8_t count = 0;
  
  for (uint8_t y = 0; y < GRID_HEIGHT && count < pixelsToShow; y++) {
    for (uint8_t x = 0; x < GRID_WIDTH && count < pixelsToShow; x++) {
      matrix.drawPixel(x, y, 150);
      count++;
    }
  }
  
  delay(3000);
  
  Serial.println();
  Serial.println("Press any button to restart...");
  
  // Wait for button press
  while (true) {
    if (digitalRead(BTN_UP) == LOW || 
        digitalRead(BTN_DOWN) == LOW ||
        digitalRead(BTN_RIGHT) == LOW || 
        digitalRead(BTN_LEFT) == LOW) {
      delay(200); // Debounce
      break;
    }
    delay(10);
  }
  
  // Restart game
  Serial.println();
  Serial.println("=== NEW GAME ===");
  initGame();
  Serial.println("Game started! Score: 0");
}

void loop() {
  if (gameOver) {
    showGameOver();
    return;
  }
  
  // Handle input every frame
  handleInput();
  
  // Move snake at controlled speed
  if (millis() - lastMoveTime >= moveDelay) {
    moveSnake();
    lastMoveTime = millis();
  }
  
  // Draw every frame
  drawGame();
  
  delay(10);  // Small delay to prevent button bouncing
}

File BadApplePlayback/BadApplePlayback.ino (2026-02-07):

#include <Wire.h>
#include <SPI.h>
#include <SPIMemory.h>

// ---------- Hardware config ----------
static const uint8_t PIN_SDB   = 9;    // IS31 SDB pin
static const uint8_t FLASH_CS  = 17;   // PB0 (often D17 on 32U4 cores)
static const uint8_t IS31_ADDR = 0x74;

// Buttons (active-low, use internal pull-ups)
static const uint8_t PIN_UP    = 0;    // Digital 0
static const uint8_t PIN_DOWN  = A5;   // ADC0
static const uint8_t PIN_RIGHT = A4;   // ADC1
static const uint8_t PIN_LEFT  = 11;   // Digital 11

// ---------- Video config ----------
static const uint16_t W = 12;
static const uint16_t H = 9;
static const uint16_t BYTES_PER_FRAME = W * H; // 108
static const uint16_t NUM_FRAMES = 6572;
static const uint32_t VIDEO_BASE_ADDR = 0x000000UL;

// ---------- IS31 registers ----------
static const uint8_t REG_PAGE  = 0xFD;
static const uint8_t PAGE_FUNC = 0x0B;
static const uint8_t PAGE_F0   = 0x00;

SPIFlash flash(FLASH_CS);

// Brightness control
static uint8_t brightness = 255;       // 0..255
static const uint8_t BRIGHT_STEP = 16; // per press
static const uint16_t BTN_DEBOUNCE_MS = 120;

static void is31_write(uint8_t reg, uint8_t val) {
  Wire.beginTransmission(IS31_ADDR);
  Wire.write(reg);
  Wire.write(val);
  Wire.endTransmission();
}

static void is31_page(uint8_t p) {
  is31_write(REG_PAGE, p);
}

static void is31_init() {
  pinMode(PIN_SDB, OUTPUT);
  digitalWrite(PIN_SDB, HIGH);
  delay(5);

  Wire.begin();
  Wire.setClock(400000);

  // Function page: exit shutdown
  is31_page(PAGE_FUNC);
  is31_write(0x0A, 0x01); // normal operation

  // Enable all LEDs (we'll only write PWM to our 12x9 window)
  is31_page(PAGE_F0);
  for (uint8_t r = 0x00; r <= 0x11; r++) is31_write(r, 0xFF);

  // Clear PWM
  for (uint16_t r = 0x24; r <= 0xB3; r++) is31_write((uint8_t)r, 0x00);
}

// Map (x,y) in our 12x9 window into IS31's 16x9 linear index
static inline uint8_t is31_index(uint8_t x, uint8_t y) {
  return (uint8_t)(y * 16 + x); // using columns 0..11 of 16
}

// Efficiently write one frame: 108 bytes -> 108 PWM regs.
// Writes 12 bytes per row, skipping unused columns 12..15.
static void is31_write_frame_scaled(const uint8_t *frame) {
  is31_page(PAGE_F0);

  uint16_t src = 0;
  for (uint8_t y = 0; y < H; y++) {
    uint8_t startReg = (uint8_t)(0x24 + is31_index(0, y));

    Wire.beginTransmission(IS31_ADDR);
    Wire.write(startReg);

    for (uint8_t x = 0; x < W; x++) {
      uint8_t v = frame[src++];
      v = (uint16_t(v) * brightness) >> 8;  // scale 0..255
      Wire.write(v);
    }

    Wire.endTransmission();
  }
}

static void handleBrightnessButtons() {
  static uint32_t lastMs = 0;
  uint32_t now = millis();
  if (now - lastMs < BTN_DEBOUNCE_MS) return;

  bool upPressed = (digitalRead(PIN_UP) == LOW);
  bool dnPressed = (digitalRead(PIN_DOWN) == LOW);

  if (upPressed || dnPressed) {
    lastMs = now;

    if (upPressed) {
      if (brightness <= 255 - BRIGHT_STEP) brightness += BRIGHT_STEP;
      else brightness = 255;
    }
    if (dnPressed) {
      if (brightness >= BRIGHT_STEP) brightness -= BRIGHT_STEP;
      else brightness = 0;
    }
  }
}

// ---------- 30 FPS timing ----------
static uint32_t nextTickUs = 0;
static uint16_t frameNo = 0;
static uint8_t frameBuf[BYTES_PER_FRAME];

void setup() {
  // Buttons (active-low)
  pinMode(PIN_UP,    INPUT_PULLUP);
  pinMode(PIN_DOWN,  INPUT_PULLUP);
  pinMode(PIN_RIGHT, INPUT_PULLUP);
  pinMode(PIN_LEFT,  INPUT_PULLUP);

  // Flash
  SPI.begin();
  if (!flash.begin()) {
    while (1) {}
  }

  // Display
  is31_init();

  nextTickUs = micros();
}

void loop() {
  handleBrightnessButtons();

  // 30 FPS = 33,333 us
  const uint32_t framePeriodUs = 33333UL;
  uint32_t now = micros();
  if ((int32_t)(now - nextTickUs) < 0) return;
  nextTickUs += framePeriodUs;

  // Read next frame from flash
  uint32_t addr = VIDEO_BASE_ADDR + (uint32_t)frameNo * BYTES_PER_FRAME;
  if (!flash.readByteArray(addr, frameBuf, BYTES_PER_FRAME)) {
    for (uint16_t i = 0; i < BYTES_PER_FRAME; i++) frameBuf[i] = 0;
  }

  // Push to IS31 (scaled by brightness)
  is31_write_frame_scaled(frameBuf);

  // Next frame
  frameNo++;
  if (frameNo >= NUM_FRAMES) frameNo = 0;
}
